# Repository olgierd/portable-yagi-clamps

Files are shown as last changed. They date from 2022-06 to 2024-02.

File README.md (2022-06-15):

# portable-yagi-clamps
3d printable clamps for DIY yagi antennas.

## How to print?

I'm using https://dkprojects.net/openscad-threads/ library to render threads. Place it in this directory in order to correctly render the STL.

I've printed mine using PLA, 0.2 mm layer, 0.4 mm nozzle, no supports.

It's designed for 22 mm PCV electrical conduit pipe as boom, but you can adjust it to any size.

Use M3x10 screw to secure a clamp on the boom.

## Dipole

You'll need SMA socket mounted using two screws.

Ground connection (right dipole arm) is made using 4 mm wide nickel strip. Make a hole, so M2.5 SMA screw will go through and route it through the cut in the thread.

Center conductor - solder a short piece of stranded wire to SMA's central pin, route through hole, add a bit of nickel tape on top, secure using glue. Voila.

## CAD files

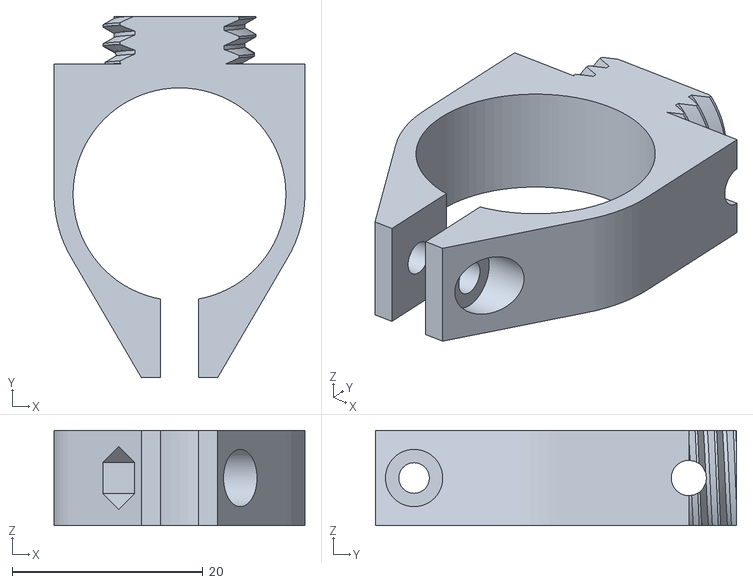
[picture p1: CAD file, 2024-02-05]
element_clamp.stl
26.3 x 37.8 x 10.0

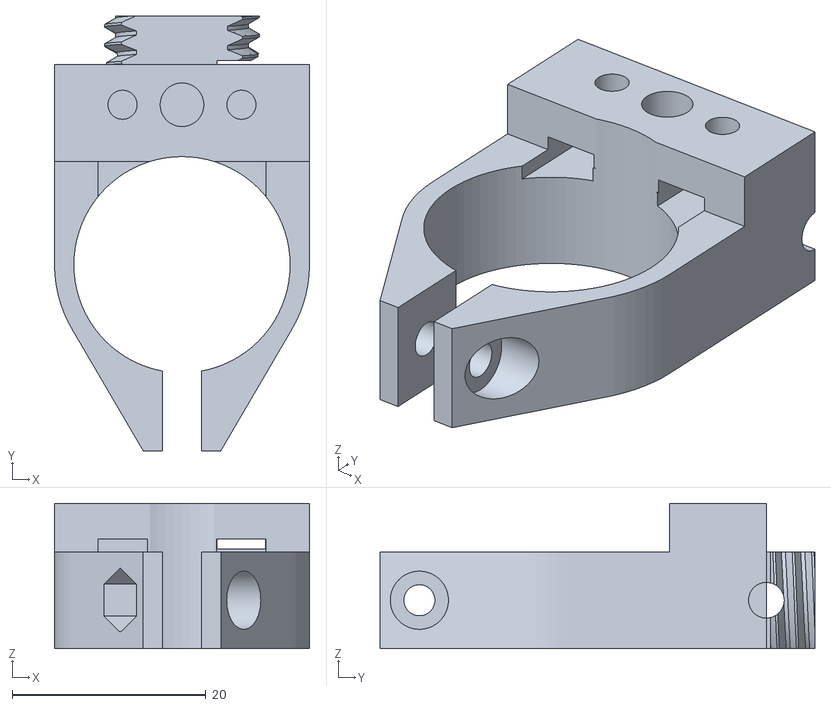
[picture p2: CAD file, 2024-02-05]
dipole_clamp.stl
26.3 x 44.8 x 15.0

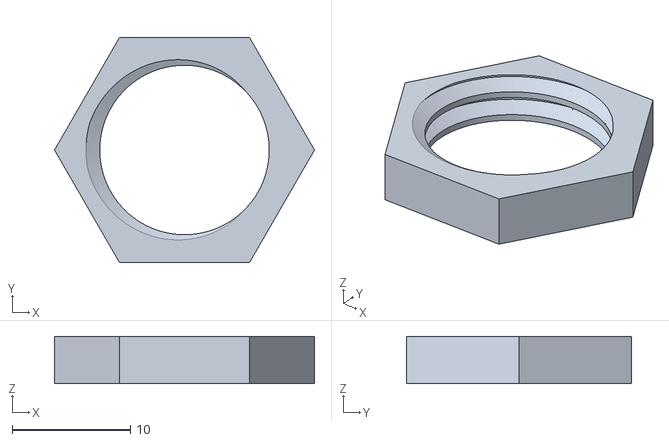
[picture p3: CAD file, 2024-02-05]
nut.stl
22.0 x 19.1 x 3.98

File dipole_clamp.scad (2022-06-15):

include <threads.scad>

$fn=80;

holder(
    dia=22.3,           // boom diameter 
    thi=2,              // wall thickness
    rise=7,             // rise element above the boom
    h=10,               // clamp height (thickness)
    thr_len=5,          // thread length
    el_hole=3.7,        // element hole diameter
    gap=4,              // width of bottom gap for screw
    scr_prot=6,         // screw protrusion
    scr_dia=3.2,        // screw hole diameter (3.2 mm for M3)
    scr_head_dia=6,     // diameter of screw head (6mm for M3)
    scr_nut_dia=6.6,    // diameter of screw nut (6.6 for M3)
    sma_thi=5,          // thickness of SMA mount
    sma_hole_dia=3,     // SMA flange hole diameter
    sma_hole_dist=6.13, // distance from SMA hole center to socket center
    sma_nut_wid=5.1,    // width of the hole for SMA nut
    sma_socket_pos=16.5 // SMA socket offset relative to boom center
);

module holder(dia, thi, h, thr_len, el_hole, gap, scr_prot, scr_dia, scr_head_dia, scr_nut_dia, rise, sma_thi, sma_hole_dia, sma_hole_dist, sma_nut_wid, sma_socket_pos) {
    
    clamp(d_in=dia, thi=thi, h=h, gap=gap, scr_prot = scr_prot, scr_dia = scr_dia, scr_head_dia = scr_head_dia, el_hole = el_hole, scr_nut_dia=scr_nut_dia, rise=rise, sma_thi=sma_thi, sma_hole_dia=sma_hole_dia, sma_hole_dist=sma_hole_dist, sma_nut_wid=sma_nut_wid, sma_socket_pos=sma_socket_pos);
    
    translate([0,dia/2+thi+0.49+rise,0])
    element_thread(d_in = dia, h=h, thr_len = thr_len, el_hole = el_hole, sma_hole_dist=sma_hole_dist);
}


module clamp(d_in, thi, h, gap, scr_prot, scr_dia, scr_head_dia, el_hole, scr_nut_dia, rise, sma_thi, sma_hole_dia, sma_hole_dist, sma_nut_wid, sma_socket_pos) {
    difference() {
        
        // main shape
        union() {
            hull() {
                // top part
                cylinder(h=h, d=d_in+thi*2, center=true);
                translate([0,d_in/2+thi+rise,0])
                cube([d_in+thi*2,1,h], center=true);
                
                // screw protrusion
                translate([0,-d_in/2-thi-scr_prot,0])
                cube([gap+thi*2,0.1,h], center=true);
            }
            
            // SMA socket mount
            translate([0,0,(h+sma_thi)/2])
            intersection() {
                hull() {
                    // top part
                    cylinder(h=sma_thi, d=d_in+thi*2, center=true);
                    translate([0,d_in/2+thi+rise,0])
                    cube([d_in+thi*2,1,sma_thi], center=true);                    
                }
                translate([0,d_in/2+rise/2+1,0])
                cube([d_in+2*thi,thi+rise+1,(h+sma_thi)*2], center=true);
            }
        }

        // boom hole
        cylinder(h=h*3, d=d_in, center=true);
        
        // clamp gap
        translate([0,-d_in/2,0])
        cube([gap,d_in,h+1], center=true);
        
        // screw hole
        translate([0,-d_in/2-(scr_prot+thi)/2,0])
        rotate([0,90,0])
        cylinder(d=scr_dia, h=d_in, center=true);
        
        // screw head
        translate([gap/2+thi,-d_in/2-(scr_prot+thi)/2,0])
        rotate([0,90,0])
        cylinder(d=scr_head_dia, h=d_in);
        
        // screw nut
        translate([-gap/2-thi,-d_in/2-(scr_prot+thi)/2,0])
        rotate([0,-90,0])
        cylinder(d=scr_nut_dia, h=d_in, $fn=6);
        
        // element undercut
        translate([0, d_in/2+thi+0.5+rise,0])
        rotate([0,90,0])
        cylinder(h=d_in*2, d=el_hole, center=true);
        
        // SMA nut hole (right one, with strip hole
        translate([sma_hole_dist,d_in/2,h/2])
        union(){ 
            cube([sma_nut_wid,d_in/2+rise-2,2.6], center=true);
            translate([0,(d_in/2+rise-2)/2,2.6/2-1/2])
            cube([5,5,1], center=true);
        }
        
        // left SMA nut hole
        translate([-sma_hole_dist,d_in/2,h/2])
        cube([sma_nut_wid,d_in/2+rise-2,2.6], center=true);
        
        // SMA screw holes
        for(x=[-1,1])
        translate([x*sma_hole_dist,sma_socket_pos,sma_thi])
        cylinder(d=3,h=10.01, center=true);
        
        // SMA center pin hole
        translate([0,sma_socket_pos,sma_thi])
        cylinder(d=4.5,h=10.01, center=true);
        
        // SMA central pin to dipole-element hole
        %translate([-2,sma_socket_pos,1])
        rotate([270,0,0])
        cylinder(d=3,h=(d_in/2+rise+1)-sma_socket_pos+1);
        

    }
    
    // SMA - support for mounting screws nut holes 
    for(x=[-1,1])
    translate([x*sma_hole_dist,sma_socket_pos,6.4])
    cube([5,5,0.2], center=true);

    // dipole elements separator
    translate([0,d_in/2+rise+thi/2+0.575,0])
    cube([0.8,el_hole/2,el_hole], center=true);
}

module element_thread(d_in, h, thr_len, el_hole, sma_hole_dist) {
    difference() {
        // flattened thread
        intersection(){ 
            rotate([-90,0,0])
            metric_thread(16, 2, thr_len, internal=false);
            cube([d_in, thr_len*2, h], center=true);
        }
        
        // main hole
        translate([0, el_hole/2, 0])
        translate([0,-el_hole/2,0])
        rotate([0,90,0])
        cylinder(h=d_in*2, d=el_hole, center=true, $fn=20);
        
        // alignment hole
        translate([0,el_hole/3,0])
        rotate([-90,0,0])
        cylinder(d1=el_hole, d2=el_hole*2.5, h=thr_len);

        // dipole ground leg stripe connection
        translate([sma_hole_dist,0.2,0])
        union(){ 
            cube([5,0.4,h+0.1], center=true);
        }
    
    }
}

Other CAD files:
element_clamp.scad
